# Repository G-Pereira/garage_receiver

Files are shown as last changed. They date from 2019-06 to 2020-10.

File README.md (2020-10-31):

# Garage Receiver
A home made receiver to replace a broken one

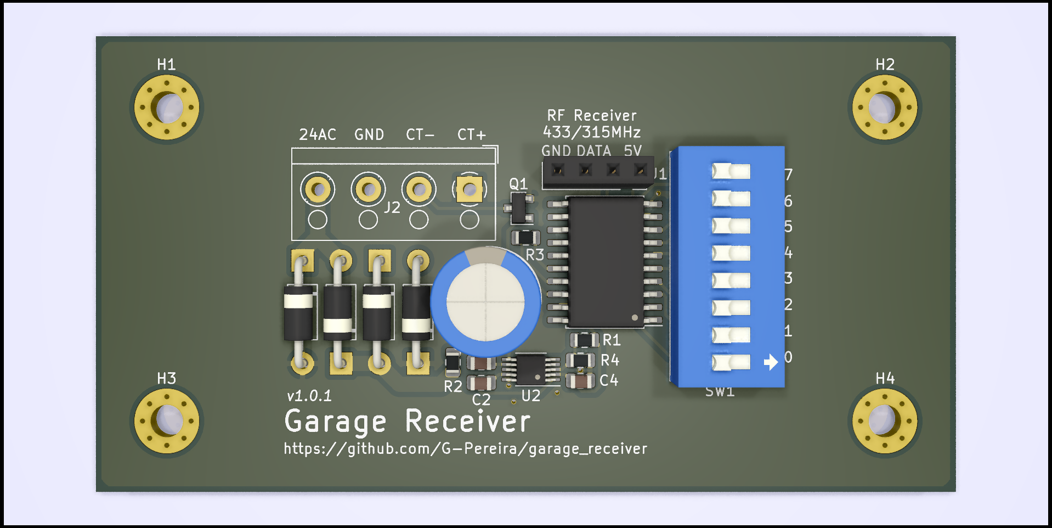
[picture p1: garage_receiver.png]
Board


## CADLAB View

View this project on [CADLAB.io](https://cadlab.io/project/1891). 

## How it works

This board works with 24V AC power supply and reponds to an RF signal which makes the input CT+ and CT- connect to each other and that makes the door open or close. The RF receiver is not included since they are readily available and some of you would need 443MHz and others 315MHz to interface with existing hardware.
You can use your existing remote by configuring the code with the switches.

## New features

In case you need more features feel free to ask for additions to the board! (Or make a pull request)

## License

Make sure to check the [License](LICENSE) file for information regarding the contents of this repository.

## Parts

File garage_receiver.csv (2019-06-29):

Reference | Quantity | Value | Footprint | Datasheet
C1 | 1 | 470u | Capacitor_THT:CP_Radial_D10.0mm_P5.00mm | ~
C2 | 1 | 1u | Capacitor_SMD:C_0805_2012Metric | ~
C4 | 1 | 10u | Capacitor_SMD:C_0805_2012Metric | ~
C5 | 1 | 100n | Capacitor_SMD:C_0805_2012Metric | ~
D1 D3 D4 D2 | 4 | 1N4007 | Diode_THT:D_DO-41_SOD81_P10.16mm_Horizontal | http://www.vishay.com/docs/88503/1n4001.pdf
H4 H3 H2 H1 | 4 | MountingHole | MountingHole:MountingHole_3.2mm_M3_Pad_Via | ~
J1 | 1 | Conn_01x04_Female | Connector_PinSocket_2.54mm:PinSocket_1x04_P2.54mm_Vertical | ~
J2 | 1 | Screw_Terminal_01x04 | TerminalBlock_RND:TerminalBlock_RND_205-00003_1x04_P5.00mm_Horizontal | ~
Q1 | 1 | 2N7002 | Package_TO_SOT_SMD:SOT-23 | https://www.fairchildsemi.com/datasheets/2N/2N7002.pdf
R1 | 1 | 62k | Resistor_SMD:R_0805_2012Metric | ~
R2 | 1 | 1k | Resistor_SMD:R_0805_2012Metric | ~
R3 | 1 | 47k | Resistor_SMD:R_0805_2012Metric | ~
R4 | 1 | 20k | Resistor_SMD:R_0805_2012Metric | ~
SW1 | 1 | SW_DIP_x08 | Button_Switch_THT:SW_DIP_SPSTx08_Slide_9.78x22.5mm_W7.62mm_P2.54mm | ~
U1 | 1 | HT12D | Package_SO:SOIC-20W_7.5x12.8mm_P1.27mm | https://www.farnell.com/datasheets/1525377.pdf
U2 | 1 | LTC3255 | Package_SO:MSOP-10-1EP_3x3mm_P0.5mm_EP1.68x1.88mm_ThermalVias | https://www.analog.com/media/en/technical-documentation/data-sheets/3245fa.pdf

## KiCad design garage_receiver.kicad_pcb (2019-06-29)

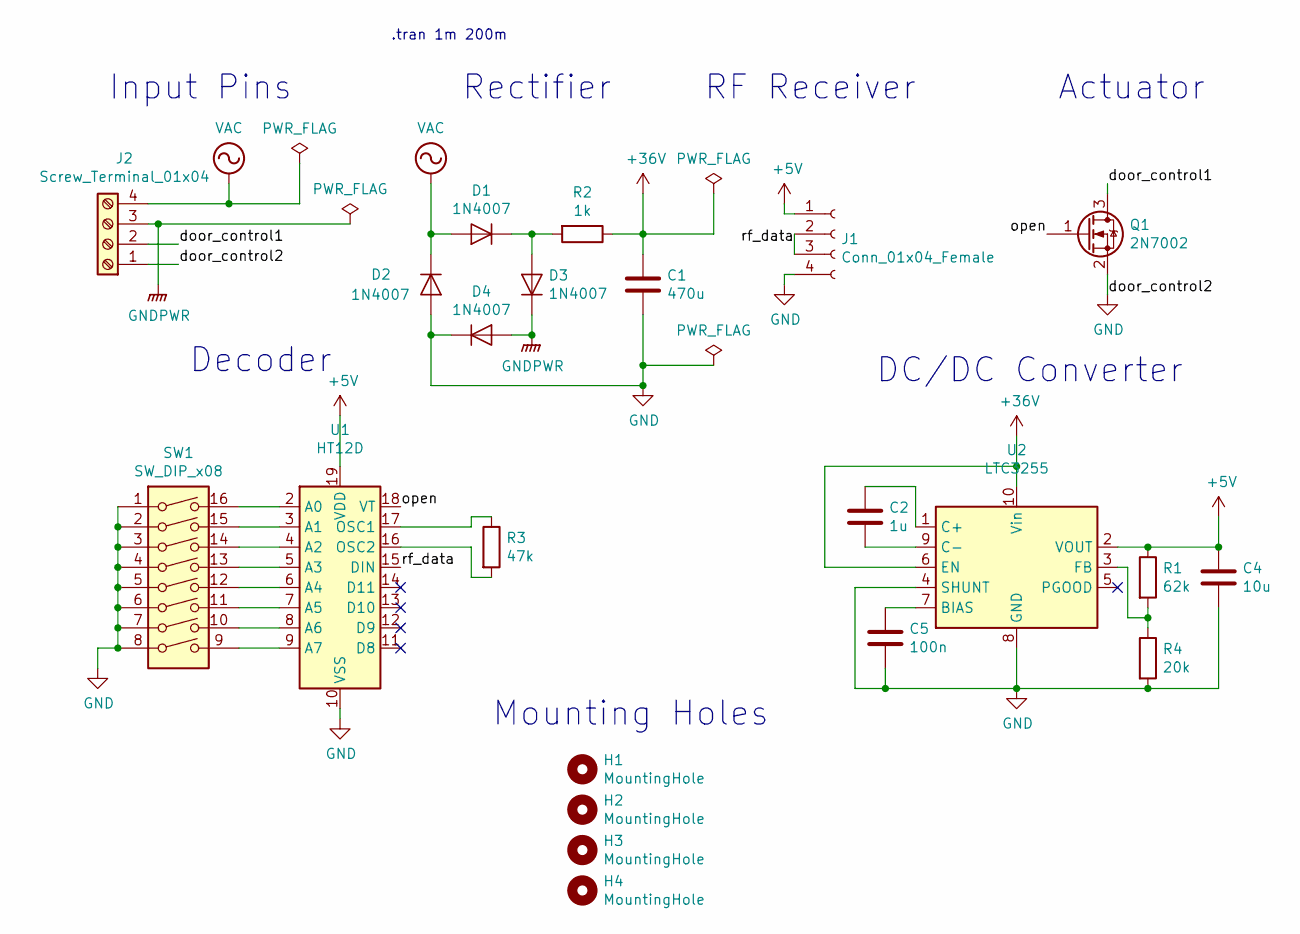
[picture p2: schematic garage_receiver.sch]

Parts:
C1: 470u; CP_Radial_D10.0mm_P5.00mm
C2: 1u; C_0805_2012Metric
C4: 10u; C_0805_2012Metric
C5: 100n; C_0805_2012Metric
D1, D2, D3, D4: 1N4007; D_DO-41_SOD81_P10.16mm_Horizontal
H1, H2, H3, H4: MountingHole; MountingHole_3.2mm_M3_Pad_Via
J1: Conn_01x04_Female; PinSocket_1x04_P2.54mm_Vertical
J2: Screw_Terminal_01x04; TerminalBlock_RND_205-00003_1x04_P5.00mm_Horizontal
Q1: 2N7002; SOT-23
R1: 62k; R_0805_2012Metric
R2: 1k; R_0805_2012Metric
R3: 47k; R_0805_2012Metric
R4: 20k; R_0805_2012Metric
SW1: SW_DIP_x08; SW_DIP_SPSTx08_Slide_9.78x22.5mm_W7.62mm_P2.54mm
U1: HT12D; SOIC-20W_7.5x12.8mm_P1.27mm
U2: LTC3255; MSOP-10-1EP_3x3mm_P0.5mm_EP1.68x1.88mm_ThermalVias

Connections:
+5V: C4.1, J1.1, R1.1, U1.19 (VDD), U2.2 (VOUT)
+36V: C1.1, R2.1, U2.6 (EN), U2.10 (Vin)
/door_control1: J2.2, Q1.3 (D)
/open: Q1.1 (G), U1.18 (VT)
/rf_data: J1.2, J1.3, U1.15 (DIN)
GND: C1.2, C4.2, C5.2, D2.2 (A), D4.1 (K), J1.4, J2.1, Q1.2 (S), R4.2, SW1.1, SW1.2, SW1.3, SW1.4, SW1.5, SW1.6, SW1.7, SW1.8, U1.10 (VSS), U2.4 (SHUNT), U2.8 (GND), U2.11 (GND)
GNDPWR: D3.1 (K), D4.2 (A), J2.3
unnamed: C2.1, U2.1 (C+)
unnamed: C2.2, U2.9 (C-)
unnamed: C5.1, U2.7 (BIAS)
unnamed: D1.1 (K), D3.2 (A), R2.2
unnamed: R1.2, R4.1, U2.3 (FB)
unnamed: R3.1, U1.17 (OSC1)
unnamed: R3.2, U1.16 (OSC2)
unnamed: SW1.9, U1.9 (A7)
unnamed: SW1.10, U1.8 (A6)
unnamed: SW1.11, U1.7 (A5)
unnamed: SW1.12, U1.6 (A4)
unnamed: SW1.13, U1.5 (A3)
unnamed: SW1.14, U1.4 (A2)
unnamed: SW1.15, U1.3 (A1)
unnamed: SW1.16, U1.2 (A0)
VAC: D1.2 (A), D2.1 (K), J2.4

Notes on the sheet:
Rectifier
DC/DC Converter
Decoder
Input Pins
RF Receiver
Actuator
Mounting Holes
.tran 1m 200m

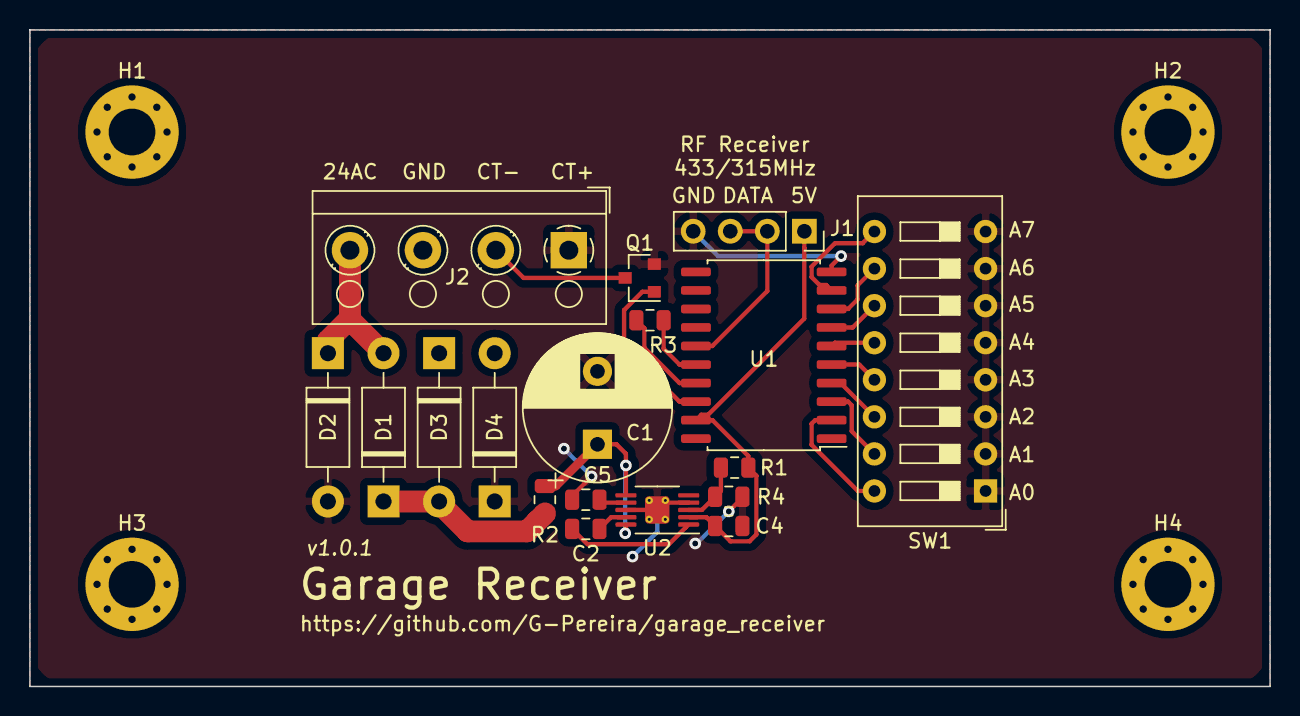
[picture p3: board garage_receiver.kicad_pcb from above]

Board: 2 copper layers, 85.0 x 45.0 mm, 22 parts (0 on the bottom side), 23 nets.

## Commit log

2019-06-20 Project Initialization
    [garage_receiver.kicad_pcb, garage_receiver.sch]
2019-06-21 Schematic complete
    [garage_receiver.sch]
2019-06-21 DC/DC Converter
    [garage_receiver.kicad_pcb, garage_receiver.sch]
2019-06-21 DC/DC Converter Controller
    [garage_receiver.kicad_pcb, garage_receiver.sch]
2019-06-21 PCB Layout
    [garage_receiver.kicad_pcb, garage_receiver.sch]
2019-06-21 Prepare for production
    [garage_receiver-B_Cu.gbr, garage_receiver-B_Mask.gbr, garage_receiver-B_SilkS.gbr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]
2019-06-21 Change Control Pin Labels
    [garage_receiver-B_Cu.gbr, garage_receiver-B_Mask.gbr, garage_receiver-B_SilkS.gbr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]
2019-06-21 Rotate Labels
    [garage_receiver-B_Cu.gbr, garage_receiver-B_Mask.gbr, garage_receiver-B_SilkS.gbr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]
2019-06-21 Fix PCB files
    [garage_receiver-B_Cu.gbr, garage_receiver-B_Mask.gbr, garage_receiver-B_SilkS.gbr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]
2019-06-21 Fix Flipped Component
    [garage_receiver-B_Cu.gbr, garage_receiver-B_Mask.gbr, garage_receiver-B_SilkS.gbr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]
2019-06-23 DC/DC converter updated to input range 4V to 48V
    [garage_receiver-B_Cu.gbr, garage_receiver-B_Mask.gbr, garage_receiver-B_SilkS.gbr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]
2019-06-23 Label secret code switches and updated BOM
    [garage_receiver-B_Cu.gbr, garage_receiver-B_Mask.gbr, garage_receiver-B_SilkS.gbr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]
2019-06-23 Fixed Soldermask Clearance
    [garage_receiver-B_Cu.gbr, garage_receiver-B_Mask.gbr, garage_receiver-B_SilkS.gbr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]
2019-06-23 Ground Screw Holes
    [garage_receiver-B_Cu.gbr, garage_receiver-B_Mask.gbr, garage_receiver-B_SilkS.gbr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]
2019-06-29 Removed Undersized and Uneded SMD Capacitor
    [garage_receiver-B_Cu.gbr, garage_receiver-B_Mask.gbr, garage_receiver-B_SilkS.gbr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]
